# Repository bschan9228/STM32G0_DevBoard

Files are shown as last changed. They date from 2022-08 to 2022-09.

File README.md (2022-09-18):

# STM32G0 DevBoard
The STM32G0 DevBoard is a devlopment board based on the STM32G070CBT6. It has a USB Type C connector that only supports power and ST-LINK to program the device. It also contains buttons, LEDs, an external oscillator, and a linear regulator. 



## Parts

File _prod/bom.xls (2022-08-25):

Comment | Designator | Footprint | JLCPCB Part #
TYPE-C-31-M-12 | J4 | HRO_TYPE-C-31-M-12 | C165948
12pUnpolarizedcapacitor,smallsymbol | C10,C11 | C_0402_1005Metric | C1547
1uUnpolarizedcapacitor | C6,C7 | C_0402_1005Metric | C52923
120RFerritebead | FB1 | L_0603_1608Metric | C710390
2k2Resistor | R1,R2,R3,R4,R9 | R_0402_1005Metric | C25879
STM32G070CBT6 | U1 | STM32G070CBT6 | C529338
10nUnpolarizedcapacitor | C5 | C_0402_1005Metric | C1524
SW_PushPushbuttonswitch,generic,twopins | SW1,SW2,SW3,SW4 | SW_PUSH_6mm_H5mm | C111609
100nUnpolarizedcapacitor,smallsymbol | C2,C3 | C_0402_1005Metric | C1525
16MHzFourpincrystal,GNDonpins2and4,smallsymbol | HSE1 | Crystal_SMD_3225-4Pin_3.2x2.5mm | C13738
500mAFuse | F1 | Fuse_0603_1608Metric | C135321
LED_4Lightemittingdiode | PC7,PC15,PC7 | LED_0603_1608Metric | C72041
LED_1Lightemittingdiode | PC14,PC6,PC14 | LED_0603_1608Metric | C72043
AMS1117-3.31ALowDropoutregulator,positive,3.3Vfixedoutput,SOT-223 | U2 | SOT-223-3_TabPin2 | C6186
4.7uUnpolarizedcapacitor,smallsymbol | C1 | C_0603_1608Metric | C19666
BLUELightemittingdiode | D5 | LED_0603_1608Metric | C2290
10kResistor | R5,R6,R7,R8 | R_0402_1005Metric | C25744
10uUnpolarizedcapacitor,smallsymbol | C8,C9 | C_0603_1608Metric | C19702

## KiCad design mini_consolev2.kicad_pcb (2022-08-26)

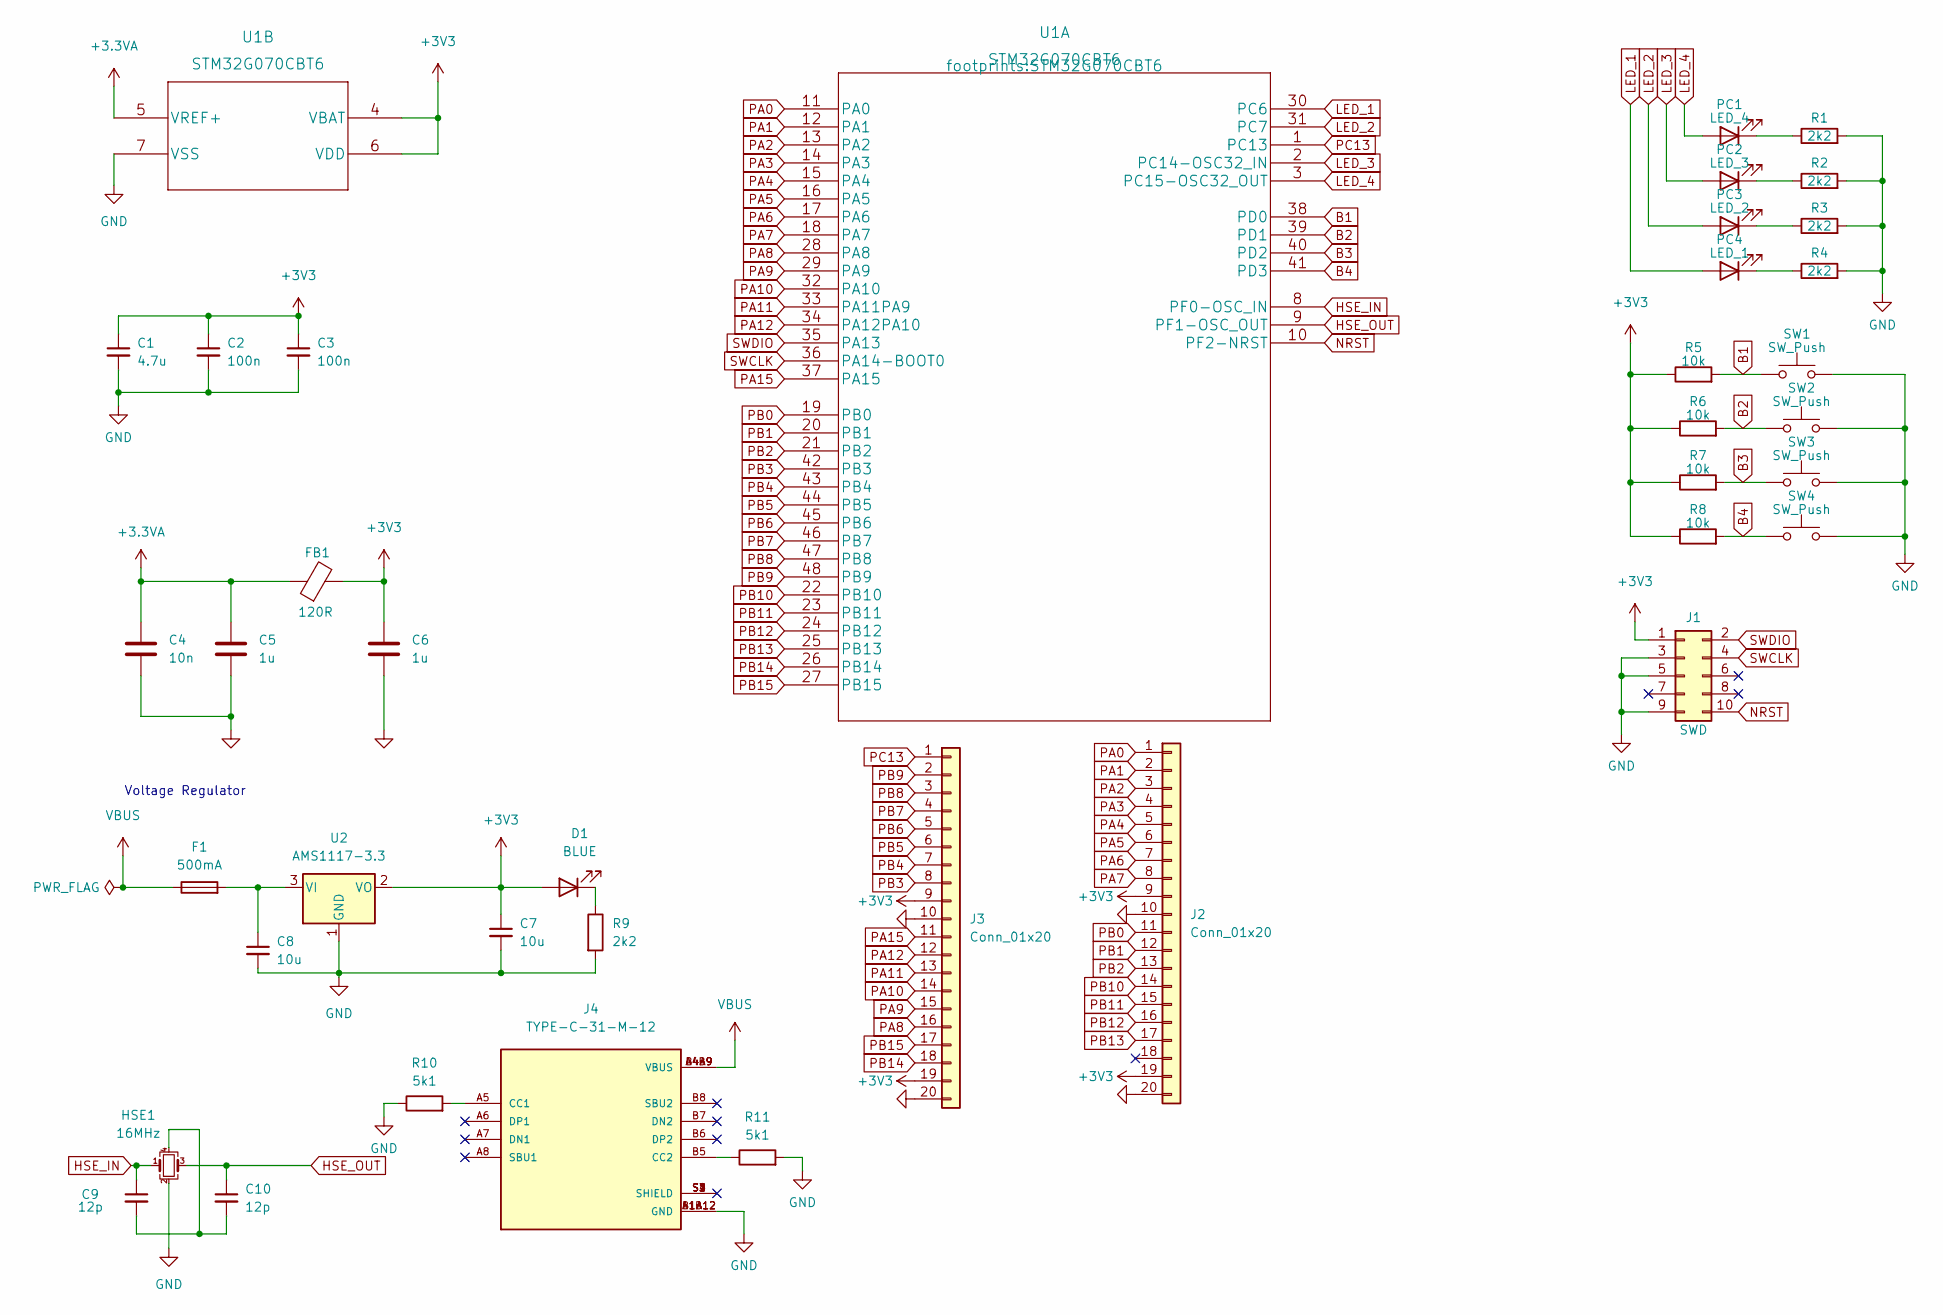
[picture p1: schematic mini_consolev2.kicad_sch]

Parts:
C1: 4.7u; C_0603_1608Metric
C2, C3: 100n; C_0402_1005Metric
C4: 10n; C_0402_1005Metric
C5, C6: 1u; C_0402_1005Metric
C7, C8: 10u; C_0603_1608Metric
C9, C10: 12p; C_0402_1005Metric
D1: BLUE; LED_0603_1608Metric
F1: 500mA; Fuse_0603_1608Metric
FB1: 120R; L_0603_1608Metric
HSE1: 16MHz; Crystal_SMD_3225-4Pin_3.2x2.5mm
J1: SWD; PinHeader_2x05_P2.54mm_Vertical
J2, J3: Conn_01x20; PinHeader_1x20_P1.27mm_Vertical
J4: TYPE-C-31-M-12; HRO_TYPE-C-31-M-12; PARTREV A
PC1: LED_4; LED_0603_1608Metric
PC2: LED_3; LED_0603_1608Metric
PC3: LED_2; LED_0603_1608Metric
PC4: LED_1; LED_0603_1608Metric
R1, R2, R3, R4, R9: 2k2; R_0402_1005Metric
R5, R6, R7, R8: 10k; R_0402_1005Metric
R10, R11: 5k1; R_0402_1005Metric
SW1, SW2, SW3, SW4: SW_Push; SW_PUSH_6mm_H5mm
U1: STM32G070CBT6
U2: AMS1117-3.3; SOT-223-3_TabPin2

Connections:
+3.3VA: C4.1, C5.1, FB1.1, U1.5 (VREF+)
+3V3: C1.1, C2.1, C3.1, C6.1, C7.1, D1.2 (A), FB1.2, J1.1, J2.9, J2.19, J3.9, J3.19, R5.1, R6.1, R7.1, R8.1, U1.4 (VBAT), U1.6 (VDD), U2.2 (VO)
B1: R5.2, SW1.1, U1.38 (PD0)
B2: R6.2, SW2.1, U1.39 (PD1)
B3: R7.2, SW3.1, U1.40 (PD2)
B4: R8.2, SW4.1, U1.41 (PD3)
GND: C1.2, C2.2, C3.2, C4.2, C5.2, C6.2, C7.2, C8.2, HSE1.2, J1.3, J1.5, J1.9, J2.10, J2.20, J3.10, J3.20, J4.A1B12 (GND), J4.B1A12 (GND), R1.2, R2.2, R3.2, R4.2, R9.2, R10.1, R11.2, SW1.2, SW2.2, SW3.2, SW4.2, U1.7 (VSS), U2.1 (GND)
HSE_IN: C9.1, HSE1.1, U1.8 (PF0-OSC_IN)
HSE_OUT: C10.1, HSE1.3, U1.9 (PF1-OSC_OUT)
LED_1: PC4.2 (A), U1.30 (PC6)
LED_2: PC3.2 (A), U1.31 (PC7)
LED_3: PC2.2 (A), U1.2 (PC14-OSC32_IN)
LED_4: PC1.2 (A), U1.3 (PC15-OSC32_OUT)
NRST: J1.10, U1.10 (PF2-NRST)
unnamed: C8.1, F1.2, U2.3 (VI)
unnamed: C9.2, C10.2, HSE1.4
unnamed: D1.1 (K), R9.1
unnamed: J4.A5 (CC1), R10.2
unnamed: J4.B5 (CC2), R11.1
unnamed: PC1.1 (K), R1.1
unnamed: PC2.1 (K), R2.1
unnamed: PC3.1 (K), R3.1
unnamed: PC4.1 (K), R4.1
PA0: J2.1, U1.11 (PA0)
PA1: J2.2, U1.12 (PA1)
PA2: J2.3, U1.13 (PA2)
PA3: J2.4, U1.14 (PA3)
PA4: J2.5, U1.15 (PA4)
PA5: J2.6, U1.16 (PA5)
PA6: J2.7, U1.17 (PA6)
PA7: J2.8, U1.18 (PA7)
PA8: J3.16, U1.28 (PA8)
PA9: J3.15, U1.29 (PA9)
PA10: J3.14, U1.32 (PA10)
PA11: J3.13, U1.33 (PA11PA9)
PA12: J3.12, U1.34 (PA12PA10)
PA15: J3.11, U1.37 (PA15)
PB0: J2.11, U1.19 (PB0)
PB1: J2.12, U1.20 (PB1)
PB2: J2.13, U1.21 (PB2)
PB3: J3.8, U1.42 (PB3)
PB4: J3.7, U1.43 (PB4)
PB5: J3.6, U1.44 (PB5)
PB6: J3.5, U1.45 (PB6)
PB7: J3.4, U1.46 (PB7)
PB8: J3.3, U1.47 (PB8)
PB9: J3.2, U1.48 (PB9)
PB10: J2.14, U1.22 (PB10)
PB11: J2.15, U1.23 (PB11)
PB12: J2.16, U1.24 (PB12)
PB13: J2.17, U1.25 (PB13)
PB14: J3.18, U1.26 (PB14)
PB15: J3.17, U1.27 (PB15)
PC13: J3.1, U1.1 (PC13)
SWCLK: J1.4, U1.36 (PA14-BOOT0)
SWDIO: J1.2, U1.35 (PA13)
VBUS: F1.1, J4.A4B9 (VBUS), J4.B4A9 (VBUS)

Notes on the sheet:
Voltage Regulator

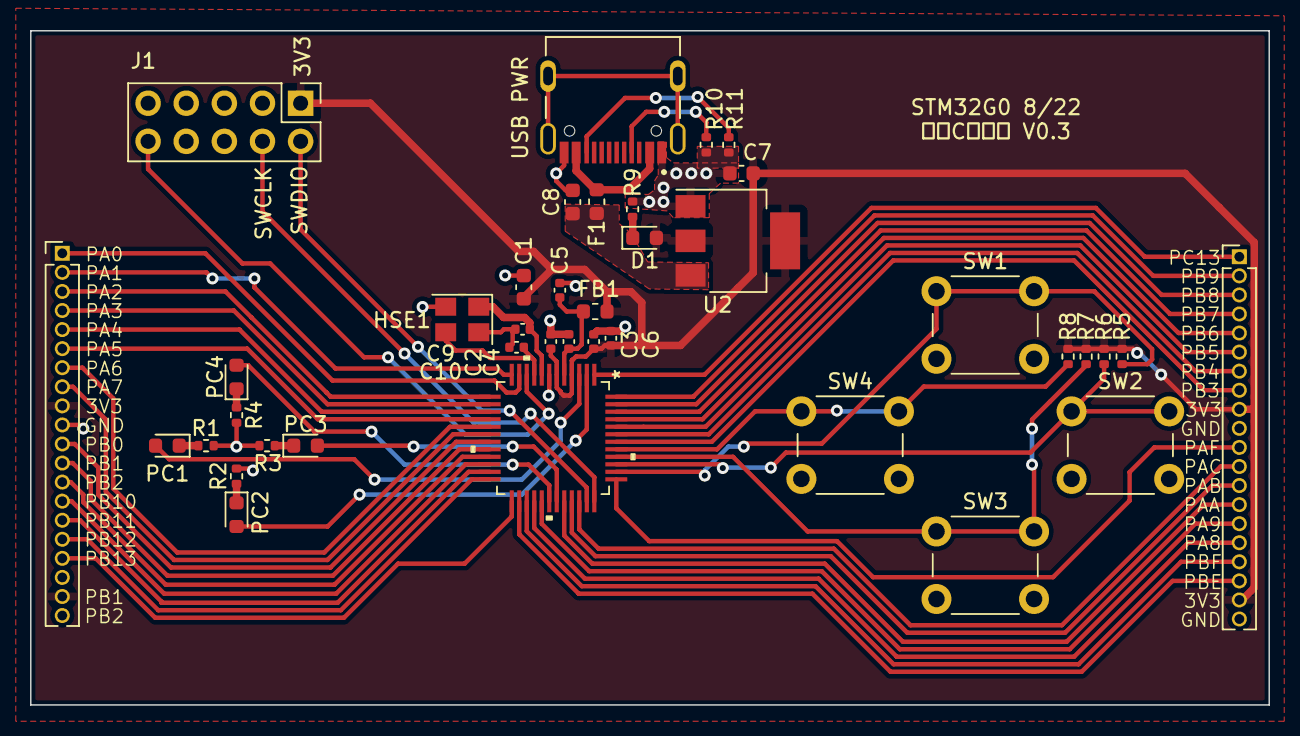
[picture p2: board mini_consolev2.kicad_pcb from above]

Board: 2 copper layers, 82.5 x 44.9 mm, 39 parts (0 on the bottom side), 57 nets.

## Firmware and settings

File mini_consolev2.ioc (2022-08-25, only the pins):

Mcu.UserName=STM32G070CBTx
PA13.Signal=SYS_SWDIO
PA14-BOOT0.Signal=SYS_SWCLK
PC6.Signal=GPIO_Output
PC7.Signal=GPIO_Output
PD0.Signal=GPIO_Input
PD1.Signal=GPIO_Input
PD2.Signal=GPIO_Input
PD3.Signal=GPIO_Input

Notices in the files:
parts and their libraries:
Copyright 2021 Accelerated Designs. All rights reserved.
